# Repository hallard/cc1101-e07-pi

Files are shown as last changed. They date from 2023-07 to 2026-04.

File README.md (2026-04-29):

# CC1101 E07 Shield for Raspberry PI

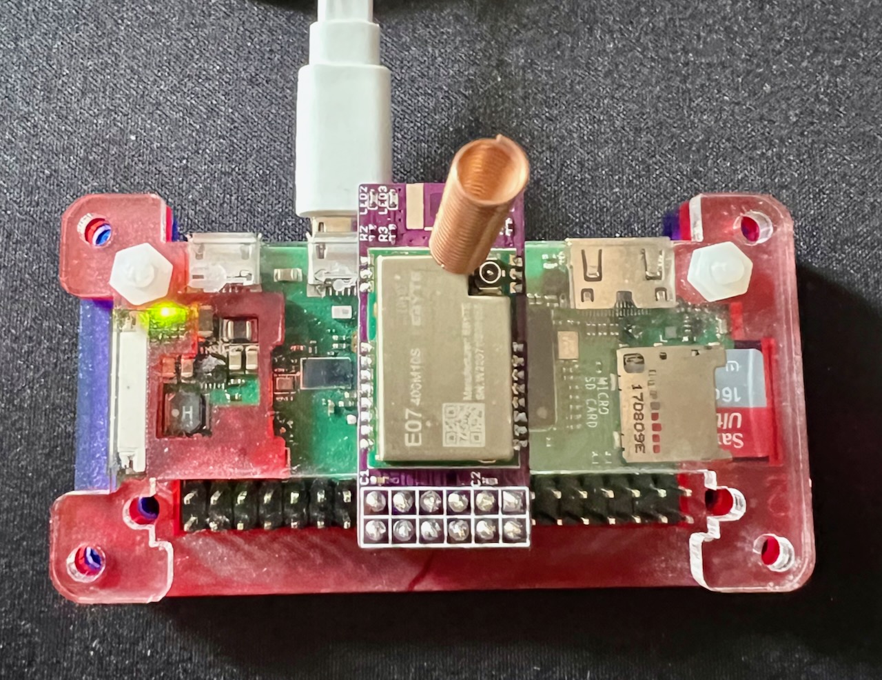
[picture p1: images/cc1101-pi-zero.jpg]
on PI Zero with spring antenna
 

This shield is used to hold [CC1101][1] Transceiver module with Raspbery PI. As soon as pinout is the same it should also works with 868 and/or 915 modules. You can easily find theese modules on Aliexpress.

It has just few minimal features, it has been created to be used for [Cyble RF 433Mhz][4] everblue reading water meter in France.

This shield can also act as a RF transceiver according already made or custom made software.    

## Features

**Version 1.0**

- Placement for E07-CC1101S 433MHz module
- Placement for choosing single Wire, SMA or u-FL Antenna type
- 3 x LED for visual indication

I received V1.0 boards from JLCPCB, they are working fine and as expected.

## Schematics

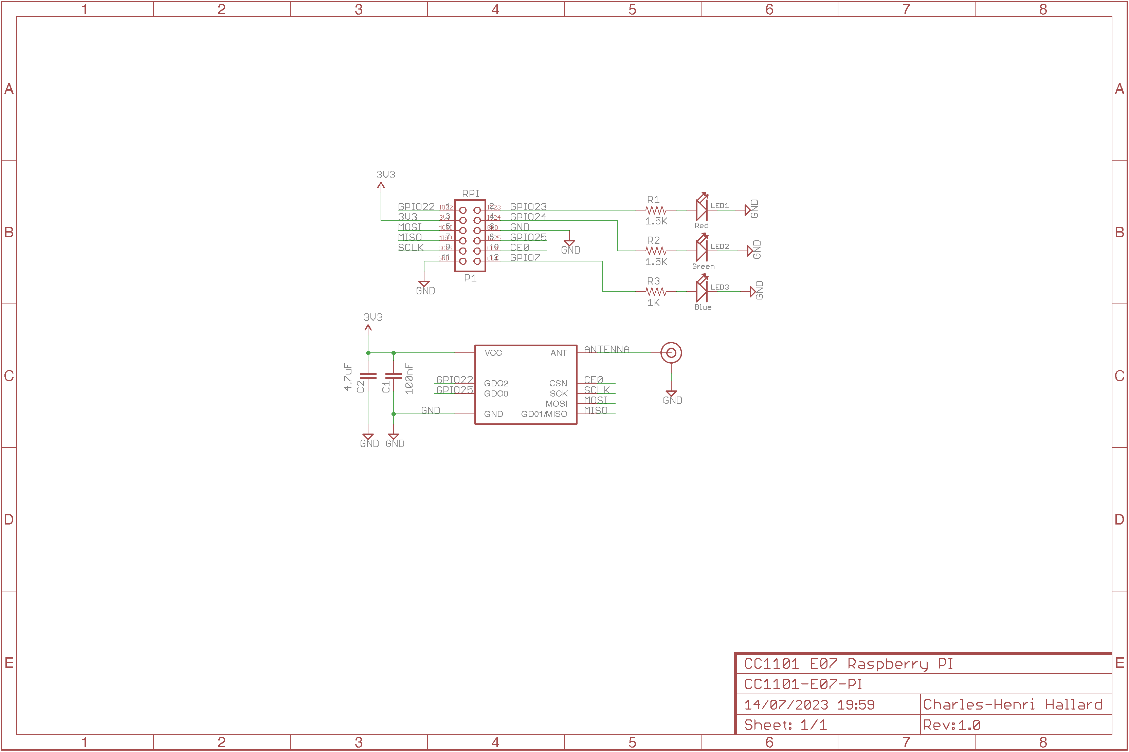
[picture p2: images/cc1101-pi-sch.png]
Schematics
    

SPI connexion is classic (MOSI/MISO/CLK), Chip Select is connected to CE0.

```
Raspberry PI         CC1101 Module 
   GPIO22  <---->  GDO2 (unused in code)
   GPIO25  <---->  GDO0

Raspberry PI      On Board LEDS
   GPIO23  <---->  LED1 (Red)
   GPIO24  <---->  LED2 (Green)
   GPIO7   <---->  LED3 (Blue)
```

## Assembled boards

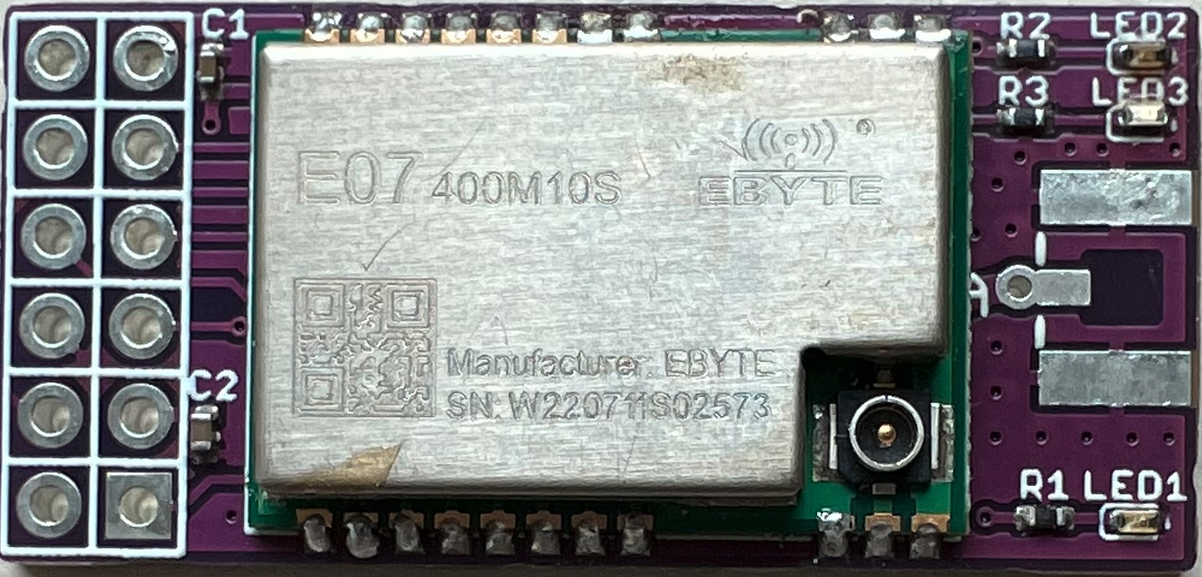
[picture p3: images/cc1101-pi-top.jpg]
Top Assembled
    

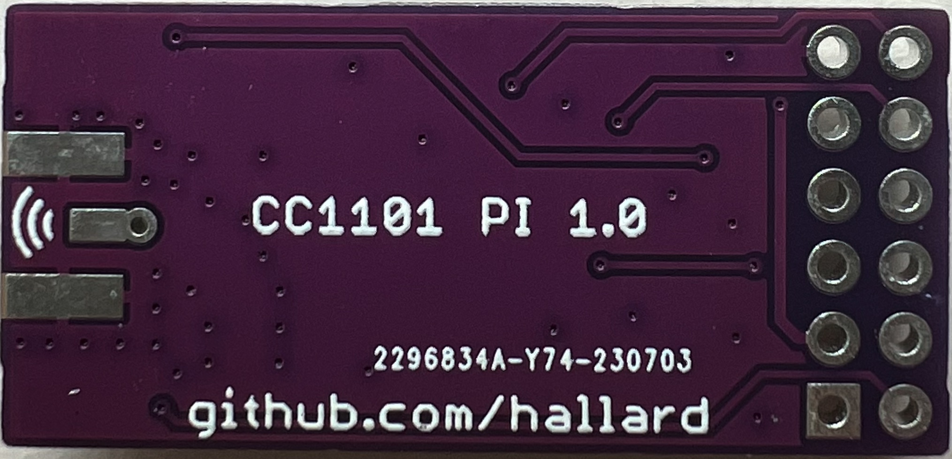
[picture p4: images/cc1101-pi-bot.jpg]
Bottom Assembled
 

## Connected to Raspberry PI

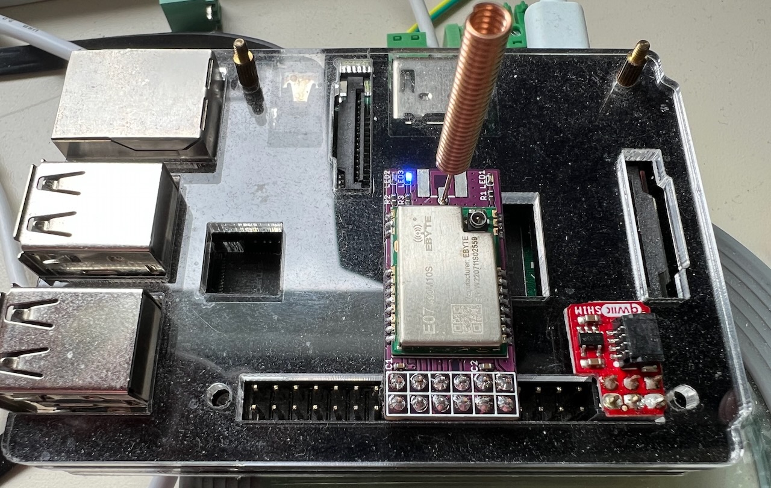
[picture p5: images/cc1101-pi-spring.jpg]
Pi with spring antenna
 

## Antenna Option

You can connect different antenna with all theese option, Spring, uFL, SMA or even 17cm wire.

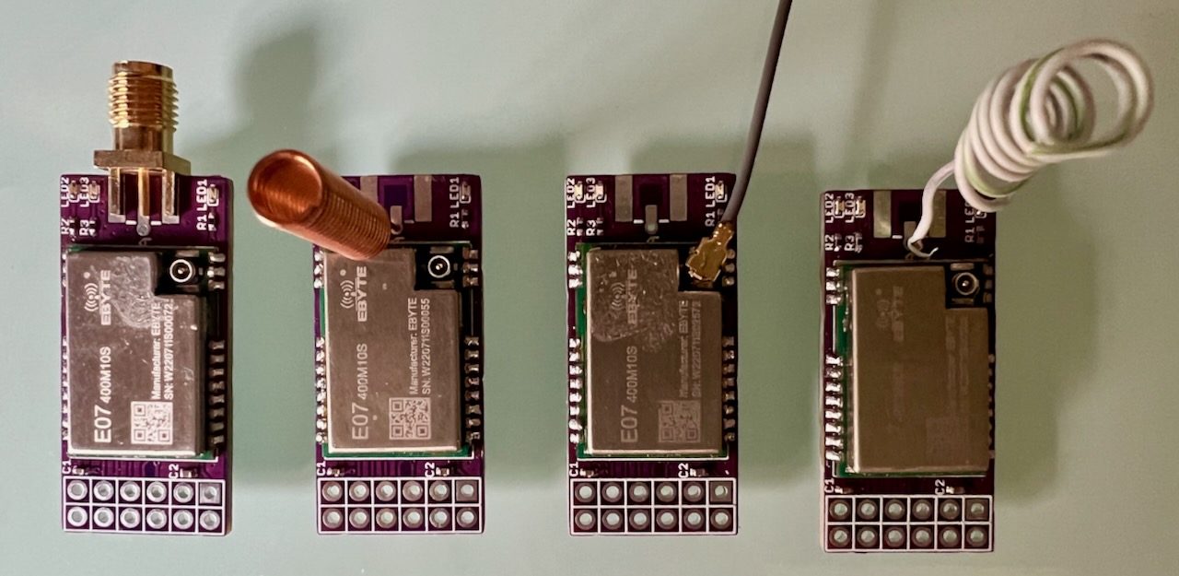
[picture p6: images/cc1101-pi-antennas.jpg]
With different antennas
 

## Software

I added some changes to the original firmware (Led, Scan, Frequency select, ...) and published on my github [everblu-meters-pi][6].
Should run out of the box with this board (including leds control), just plug, and play.

All credits to original code (but also **all the hard work** to get things working) are from [here][4] then exposed to github [here][5].

## License



This work is licensed under a [Creative Commons Attribution-NonCommercial-ShareAlike 4.0 International License](https://creativecommons.org/licenses/by-nc-sa/4.0/).
If you want to do commercial stuff with this project, please contact [CH2i company](https://ch2i.eu/en#support) so we can organize an simple agreement.

## Lazy building your own? 

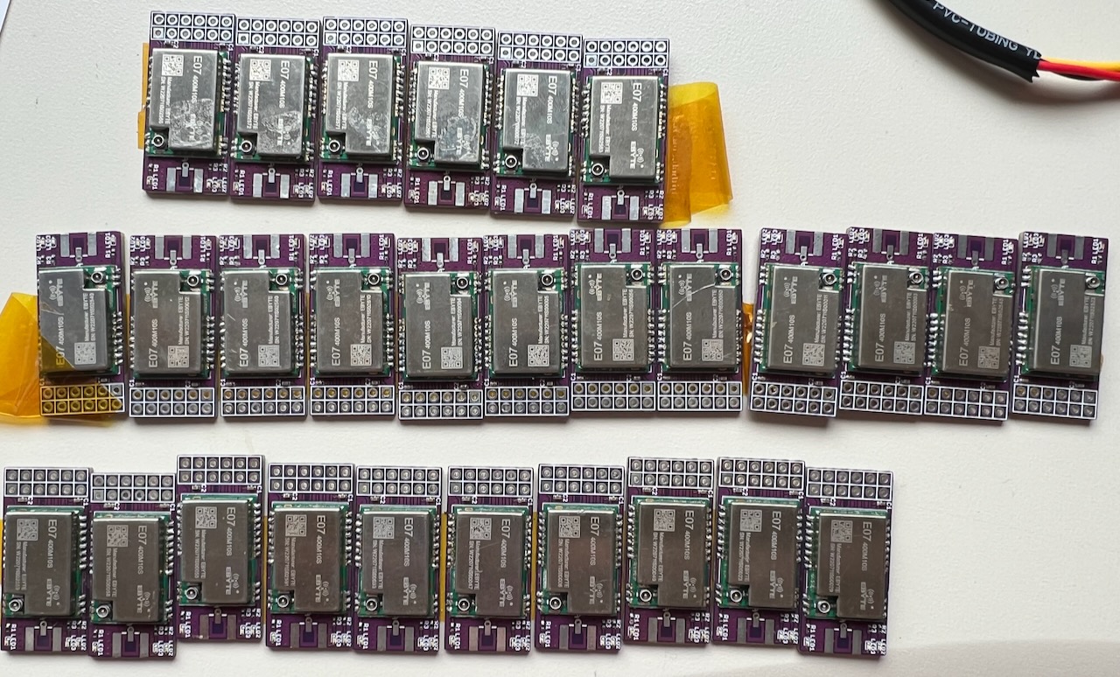
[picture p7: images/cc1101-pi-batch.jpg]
CC1101-PI Batch
 

I've put some of these board on [tindie][7], so you can order one (EU only) from my [store][7]. They are also available on [Lectronz](https://lectronz.com/products/cc1101-pi).

European customers may prefer ordering on Lectronz, which offers additional payment methods and pricing in Euros.





## Misc

See news and other projects on my [blog][2] 

[1]: https://www.cdebyte.com/products/E07-M1101S
[2]: https://hallard.me
[3]: https://oshpark.com/shared_projects/BVwV2j3b
[4]: http://www.lamaisonsimon.fr/wiki/doku.php?id=maison2:compteur_d_eau:compteur_d_eau
[5]: https://github.com/neutrinus/everblu-meters
[6]: https://github.com/hallard/everblu-meters-pi
[7]: https://www.tindie.com/products/hallard/cc1101-mini-shield-for-raspberry-pi

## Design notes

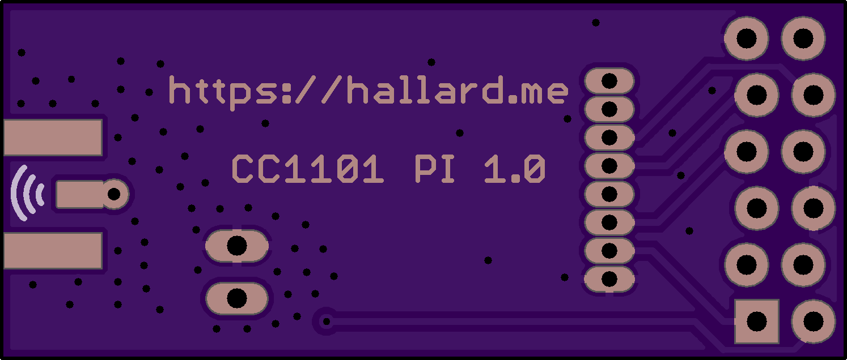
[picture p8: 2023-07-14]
images/cc1101-pi-bot.png

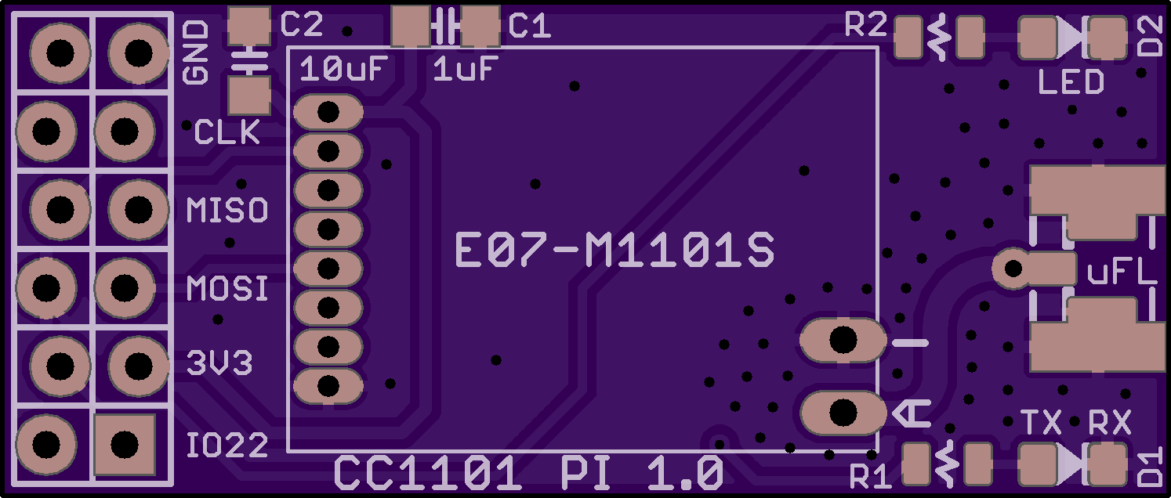
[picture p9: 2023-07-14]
images/cc1101-pi-top.png

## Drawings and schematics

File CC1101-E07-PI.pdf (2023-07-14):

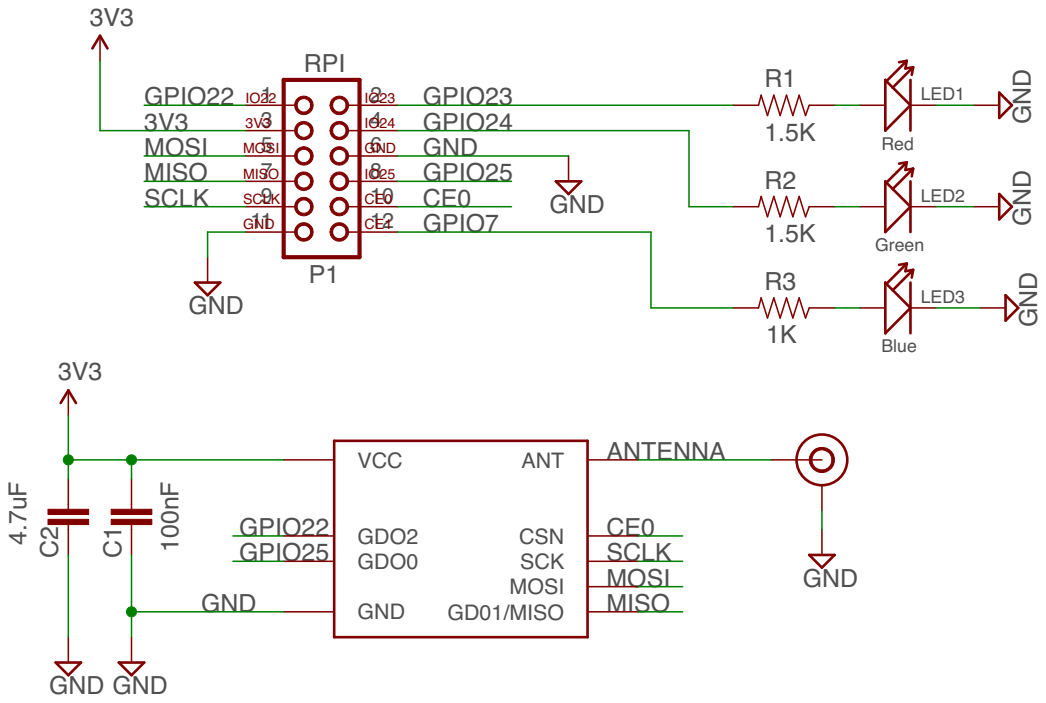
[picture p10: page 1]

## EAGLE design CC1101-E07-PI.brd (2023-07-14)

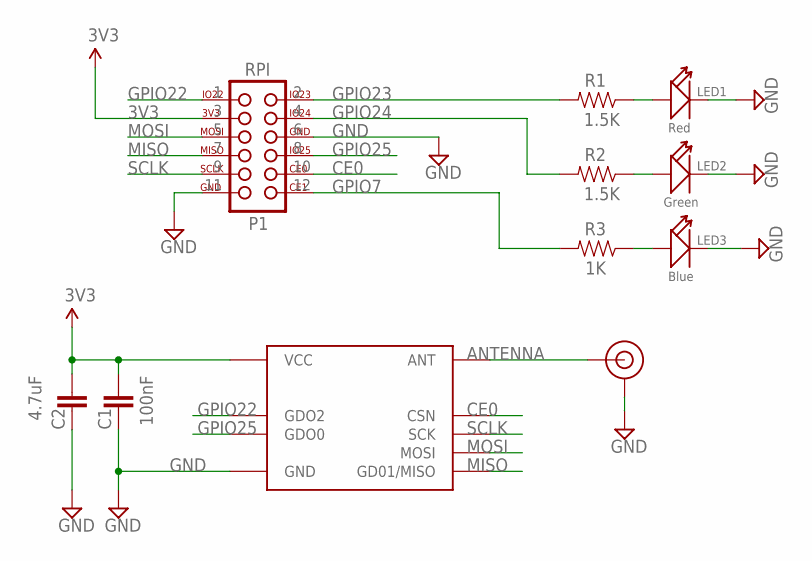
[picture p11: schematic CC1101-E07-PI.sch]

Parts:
C1: 100nF; 0402-CAP
C2: 4.7uF; 0402-CAP
J1: 2X6_BOTTOM; 2X06
J$1: ANTENNASMA; SMA_PAD
LED1: Red; LED-0402
LED2: Green; LED-0402
LED3: Blue; LED-0402
R1, R2: 1.5K; 0402-RES
R3: 1K; 0402-RES
U1: E07-400M10S; E07-900M10S

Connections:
3V3: C1.2, C2.2, J1.3 (17), U1.9 (VCC)
ANTENNA: J$1.ANT0 (ANT), J$1.ANT1 (ANT), J$1.ANT2 (ANT), U1.21 (ANT)
CE0: J1.10 (24), U1.19 (CSN)
GND: C1.1, C2.1, J1.6 (20), J1.11 (25), J$1.GND3 (GND), J$1.GND4 (GND), J$1.GND5 (GND), J$1.GND6 (GND), LED1.-, LED2.-, LED3.-, U1.1 (GND), U1.2 (GND), U1.3 (GND), U1.4 (GND), U1.5 (GND), U1.11 (GND), U1.12 (GND), U1.20 (GND), U1.22 (GND)
GPIO7: J1.12 (26), R3.2
GPIO22: J1.1 (15), U1.14 (GDO2)
GPIO23: J1.2 (16), R1.2
GPIO24: J1.4 (18), R2.2
GPIO25: J1.8 (22), U1.15 (GDO0)
MISO: J1.7 (21), U1.16 (GD01/MISO)
MOSI: J1.5 (19), U1.17 (MOSI)
unnamed: LED1.+, R1.1
unnamed: LED2.+, R2.1
unnamed: LED3.+, R3.1
SCLK: J1.9 (23), U1.18 (SCK)

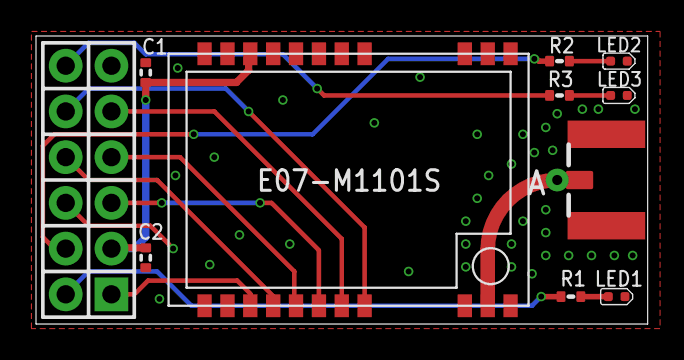
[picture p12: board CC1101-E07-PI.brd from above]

Board: 2 copper layers, 34.0 x 16.0 mm, 11 parts (0 on the bottom side), 15 nets.

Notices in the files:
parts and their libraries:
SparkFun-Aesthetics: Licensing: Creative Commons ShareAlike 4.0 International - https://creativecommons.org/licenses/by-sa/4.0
